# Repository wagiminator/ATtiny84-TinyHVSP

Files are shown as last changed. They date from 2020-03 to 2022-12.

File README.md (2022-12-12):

# TinyHVSP - High-Voltage Serial Programmer based on ATtiny24/44/84
Stand-alone high-voltage serial programmer and fuse resetter for ATtiny 13/25/45/85. This project was superseded by the more versatile [TinyCalibrator](https://github.com/wagiminator/ATtiny84-TinyCalibrator).

- Project Video (YouTube): https://youtu.be/2Q7D2RwkOMg
- Design Files (EasyEDA): https://easyeda.com/wagiminator/z-attiny84-tinyhvprogrammer

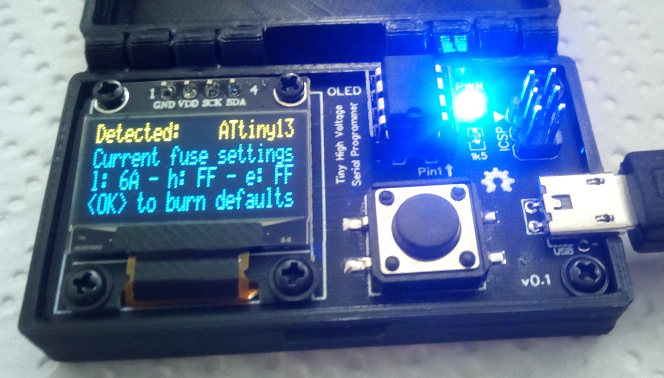
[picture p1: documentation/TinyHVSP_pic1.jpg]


# Hardware
The TinyHVSP is supplied with 5V via a [Micro USB connector](https://aliexpress.com/wholesale?SearchText=micro+usb+2pin+dip). The [ATtiny24/44/84](http://ww1.microchip.com/downloads/en/devicedoc/Atmel-7701_Automotive-Microcontrollers-ATtiny24-44-84_Datasheet.pdf) was chosen as the microcontroller for the TinyHVSP because it has the necessary number of GPIO pins. To generate the 12V for the High-Voltage Serial Programmer, an inexpensive [MT3608](https://datasheet.lcsc.com/szlcsc/XI-AN-Aerosemi-Tech-MT3608_C84817.pdf) boost converter IC was used. The 12V is controlled by a BJT and applied to the RESET pin of the target ATtiny if necessary. The remaining programming lines to the target are protected against a short circuit with resistors. The user interface utilizes one button and a [128x64 pixels OLED display](http://aliexpress.com/wholesale?SearchText=128+64+0.96+oled+new+4pin).

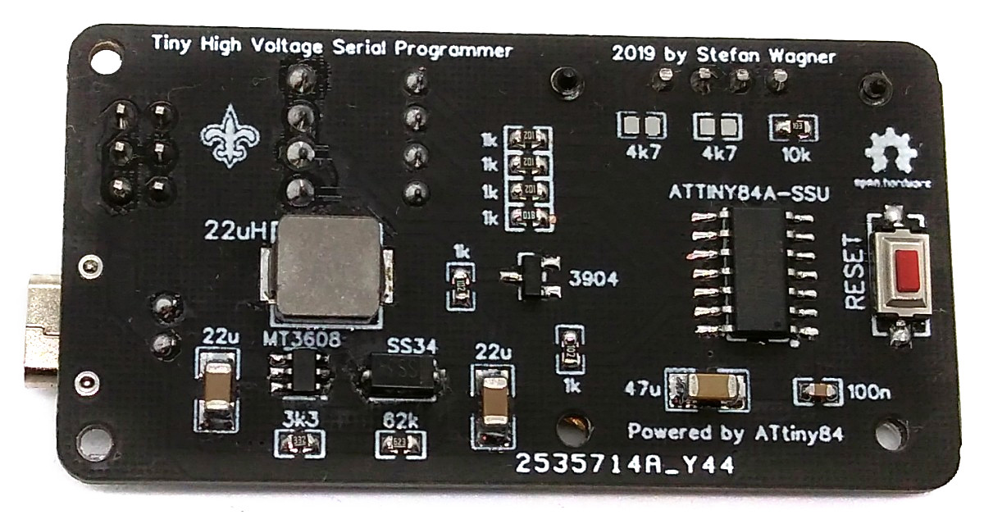
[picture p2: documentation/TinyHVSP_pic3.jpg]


# Software
## High-Voltage Serial Programmer
The code for the High-Voltage Serial Programmer (HVSP) is quite unspectacular. Simply put, for each action, a series of instructions are sent over the data lines to the target ATtiny and the corresponding response is read. The process and the instructions are well described in the data sheet.



## I²C OLED Implementation
The I²C protocol implementation is based on a crude bitbanging method. It was specifically designed for the limited resources of ATtiny10 and ATtiny13, but it works with some other AVRs (including the ATtiny24/44/84) as well. The functions for the OLED are adapted to the SSD1306 OLED module, but they can easily be modified to be used for other modules. In order to save resources, only the basic functionalities which are needed for this application are implemented. For a detailed information on the working principle of the I²C OLED implementation visit [TinyOLEDdemo](https://github.com/wagiminator/attiny13-tinyoleddemo).

## Compiling and Uploading
### If using the Arduino IDE
- Make sure you have installed [ATtinyCore](https://github.com/SpenceKonde/ATTinyCore).
- Go to **Tools -> Board -> ATtinyCore** and select **ATtiny24/44/84(a) (No bootloader)**.
- Go to **Tools** and choose the following board options:
  - **Chip:**           ATtiny24(a) or 44(a) or 84(a) (depending on your chip)
  - **Clock:**          8 MHz (internal)
  - **Millis/Micros:**  disabled
  - Leave the rest at the default settings
- Connect your programmer to your PC and to the ICSP header of the device.
- Go to **Tools -> Programmer** and select your ISP programmer (e.g. [USBasp](https://aliexpress.com/wholesale?SearchText=usbasp)).
- Go to **Tools -> Burn Bootloader** to burn the fuses.
- Open TinyHVSP sketch and click **Upload**.

### If using the precompiled hex-file
- Make sure you have installed [avrdude](https://learn.adafruit.com/usbtinyisp/avrdude).
- Connect your programmer to your PC and to the ICSP header of the device.
- Open a terminal.
- Navigate to the folder with the hex-file.
- Execute the following command (if necessary replace "t84" with the chip you use and "usbasp" with the programmer you use):
  ```
  avrdude -c usbasp -p t84 -U lfuse:w:0xe2:m -U hfuse:w:0xd7:m -U efuse:w:0xff:m -U flash:w:tinyhvsp.hex
  ```

### If using the makefile (Linux/Mac)
- Make sure you have installed [avr-gcc toolchain and avrdude](http://maxembedded.com/2015/06/setting-up-avr-gcc-toolchain-on-linux-and-mac-os-x/).
- Connect your programmer to your PC and to the ICSP header of the device.
- Open a terminal.
- Navigate to the folder with the makefile and the Arduino sketch.
- Run `DEVICE=attiny84 PROGRMR=usbasp make install` to compile, burn the fuses and upload the firmware (change DEVICE and PROGRMR accordingly).

# Operating Instructions
1. Connect a 5V power supply to the micro USB port.
2. Place the ATtiny13/25/45/85 in the IC socket. Use an [SOP adapter](https://aliexpress.com/wholesale?SearchText=sop-8+150mil+200mil+adapter) for SMD parts.
3. Press OK-button and follow the instructions on the display.

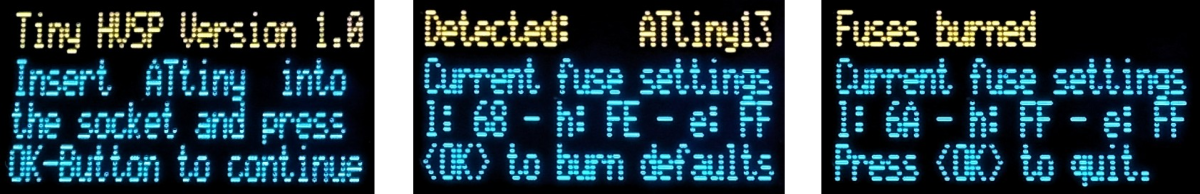
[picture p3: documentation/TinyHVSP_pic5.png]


# References, Links and Notes
1. [TinyCalibrator](https://github.com/wagiminator/ATtiny84-TinyCalibrator)
2. [AVR HVSP by Paul Willoughby](http://www.rickety.us/2010/03/arduino-avr-high-voltage-serial-programmer/)
3. [AVR HV Programmer by Jeff Keyzer](https://mightyohm.com/blog/2008/09/arduino-based-avr-high-voltage-programmer/)
4. [PiggyFuse by Ralph Doncaster](https://nerdralph.blogspot.com/2018/05/piggyfuse-hvsp-avr-fuse-programmer.html)
5. [I²C OLED Tutorial](https://github.com/wagiminator/attiny13-tinyoleddemo)
6. [ATtiny24/44/84 Datasheet](http://ww1.microchip.com/downloads/en/devicedoc/Atmel-7701_Automotive-Microcontrollers-ATtiny24-44-84_Datasheet.pdf)
7. [ATtiny13A Datasheet](http://ww1.microchip.com/downloads/en/DeviceDoc/doc8126.pdf)
8. [ATtiny25/45/85 Datasheet](https://ww1.microchip.com/downloads/en/DeviceDoc/Atmel-2586-AVR-8-bit-Microcontroller-ATtiny25-ATtiny45-ATtiny85_Datasheet.pdf)

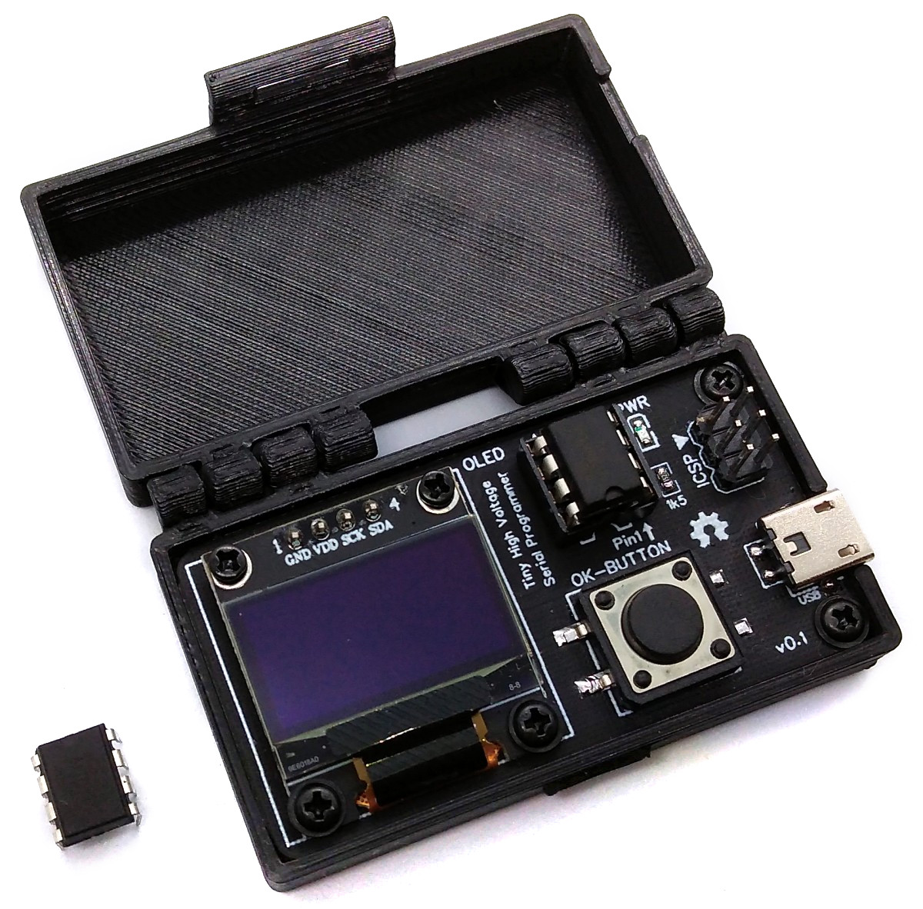
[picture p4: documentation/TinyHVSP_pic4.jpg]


# License


This work is licensed under Creative Commons Attribution-ShareAlike 3.0 Unported License. 
(http://creativecommons.org/licenses/by-sa/3.0/)

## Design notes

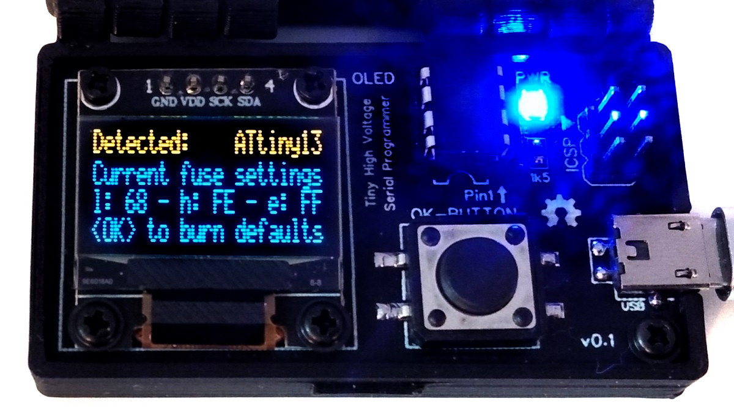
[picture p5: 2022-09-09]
documentation/TinyHVSP_pic2.jpg

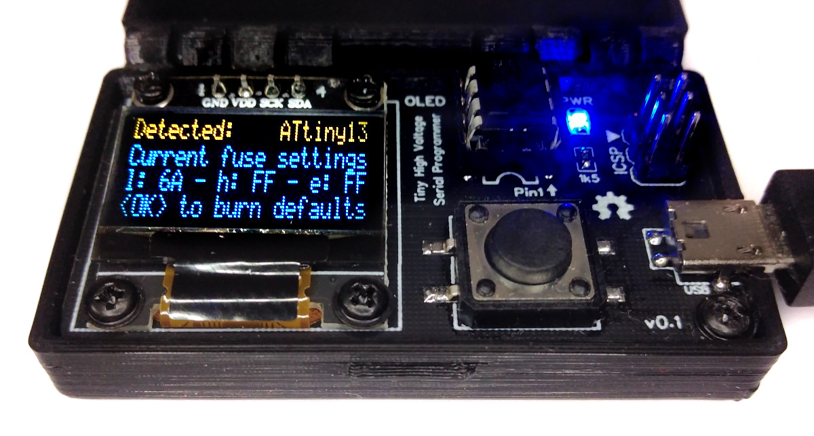
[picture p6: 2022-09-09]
documentation/TinyHVSP_pic6.jpg

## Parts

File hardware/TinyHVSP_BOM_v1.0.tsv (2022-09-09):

ID | Name | Designator | Footprint | Quantity | Manufacturer Part | Manufacturer | Supplier | Supplier Part
1 | 2n3904S | Q1 | SOT-23_1 | 1 | 2n3904S-RTK/PS | KEC | LCSC | C18536
2 | 22uH | L1 | IND-706628_IND_0630_VAN | 1 | 0630CDMCCDS-220MC | Sumida | LCSC | C167293
3 | 1k | R11,R10,R12,R13,R14 | 603 | 5 | 0603WAF1001T5E | UniOhm | LCSC | C21190
4 | 4k7 | R3,R4 | 603 | 2 | 0603WAF4701T5E | UniOhm | LCSC | C23162
5 | 62k | R5 | 603 | 1 | 0603WAF6202T5E | UniOhm | LCSC | C23221
6 | 1k5 | R2 | 603 | 1 | 0603WAF1501T5E | UniOhm | LCSC | C22843
7 | 10k | R1 | 603 | 1 | 0603WAF1002T5E | UniOhm | LCSC | C25804
8 | 3k3 | R6 | 603 | 1 | 0603WAF3301T5E | UniOhm | LCSC | C22978
9 | SMD-Tactile-Switch-12X12X6MM | SW1 | SW-SMD_4PIN-L12.0-W12.0-H6.0 | 1 | SMD Tactile Switch 12X12X6MM | ReliaPro | LCSC | C36226
10 | ATTINY84A-SSU | U1 | SOIC-14_150MIL | 1 | ATTINY84A-SSU | MICROCHIP | LCSC | C144333
11 | OLED | OLED | OLED | 1 | ?
12 | USB PWR Connector | USB | USB PWR CONNECTOR | 1 | KH-MICRO-SMT.J-2P | Shenzhen Kinghelm Elec | LCSC | C2688799
13 | MT3608 | U2 | SOT-23-6 | 1 | MT3608 | AEROSEMI | LCSC | C84817
14 | ICSP-6 | ICSP | ICSP-6-B | 1 | C65114 | BOOMELE | LCSC | C65114
15 | 3x6x2.5 | RESET | KEY-3.0*6.0 | 1 | 3x6x2.5Red head high temperature | ReliaPro | LCSC | C46491
16 | 100n | C1 | 603 | 1 | CC0603KRX7R9BB104 | YAGEO | LCSC | C14663
17 | 1k | R9 | 1206 | 1 | 1206W4F1001T5E | UniOhm | LCSC | C4410
18 | 47u | C2 | 1206 | 1 | 1206F476M160NT | FH | LCSC | C30300
19 | 22u | C3,C4 | 1206 | 2 | CL31A226KAHNNNE | SAMSUNG | LCSC | C12891
20 | PWR | LED1 | LED-0603 | 1 | 19-217/BHC-ZL1M2RY/3T | EVERLIGHT | LCSC | C72041
21 | SS34 | D1 | SMA(DO-214AC) | 1 | SS34 | Yenji | LCSC | C142458
22 | DIP8 Socket | ATTINY | DIP-8 | 1 | DS1009-08AT1NX-0A2 | CONNFLY | LCSC | C72124

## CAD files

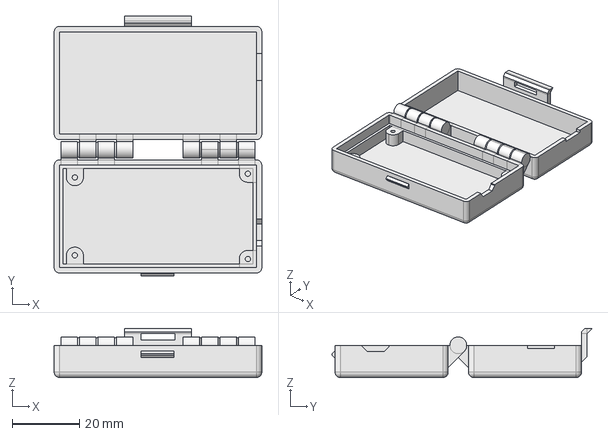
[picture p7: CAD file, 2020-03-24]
3dprint/TinyHVSP.fcstd
61.8 x 77.4 x 14.6 mm

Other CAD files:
3dprint/TinyHVSP.stl

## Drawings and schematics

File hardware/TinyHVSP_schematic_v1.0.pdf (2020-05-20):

ATtiny84 Microcontroller | Connectors

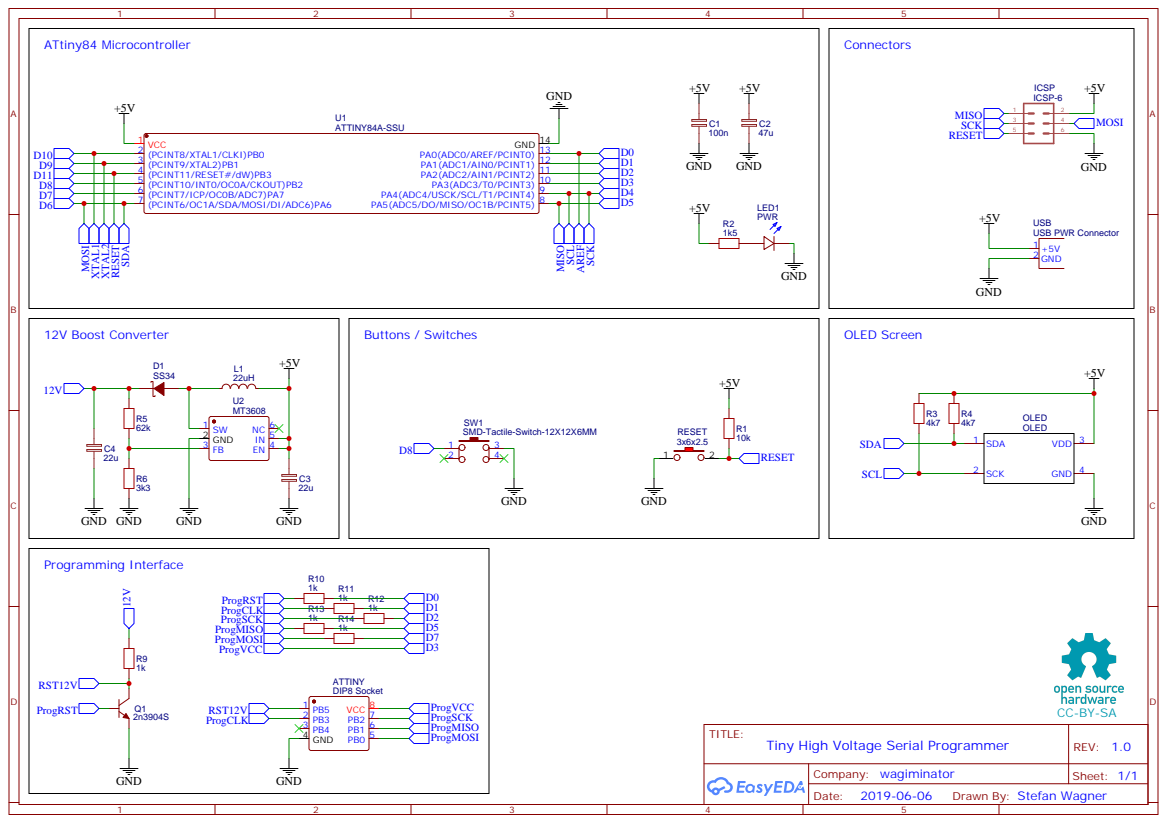
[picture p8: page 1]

Drawn By: Stefan Wagner

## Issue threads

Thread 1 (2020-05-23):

farbiges oled display

hspeedy, 2020-05-23:
welches display wurde hier verwendet? ich suche nach einem farbigen oled.
die bisher gefundenen waren immer monochrom.

wagiminator, 2022-11-24:
Das hier ist eigentlich auch monochrom: die erste Zeile wird immer gelb, der Rest wird immer blau dargestellt.

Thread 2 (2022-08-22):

Not working with attiny25/45/85

wareck, 2022-08-22:
I don't understand, it work perfectly with attiny13 but with tiny25 or tiny45 it do not work.
Have you got an idea to fix this ?

wagiminator, 2022-11-24:
That's weird. Can you otherwise program the ATtiny25/45 normally?

wareck, 2022-11-24:
Hello
sorry this message was old, I found why not working.
It's because I had some attiny25 which not have same signatures (probably fake or re-branded chips
I add a case switch with this weird signature and works perfectly

 I also add a dip socket and connections for attiny84 with the same design/software , I just add some line to recogneise chip and give right fuse for attiny84

 thanks you a lot
 you cas close this issue

best regards
Olivier

wagiminator, 2022-11-24:
Well that sounds good, thank you very much!

Closed 2022-11-24.

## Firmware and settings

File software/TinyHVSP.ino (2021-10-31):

// ===================================================================================
// Project:   TinyHVSP - AVR High-Voltage Serial Programmer based on ATtiny84
// Version:   v1.0
// Year:      2019
// Author:    Stefan Wagner
// Github:    https://github.com/wagiminator
// EasyEDA:   https://easyeda.com/wagiminator
// License:   http://creativecommons.org/licenses/by-sa/3.0/
// ===================================================================================
//
// Description:
// ------------
// Stand-alone AVR High-Voltage Serial Programmer for ATtiny13/25/45/85
// using an ATtiny84 for bit-banging the protocol according to the
// respective datasheets.
//
// References:
// -----------
// based on the work of Jeff Keyzer
// http://mightyohm.com
// and Paul Willoughby
// http://www.rickety.us/2010/03/arduino-avr-high-voltage-serial-programmer/
//
// The I²C OLED implementation is based on TinyOLEDdemo
// https://github.com/wagiminator/ATtiny13-TinyOLEDdemo
//
// OLED font was adapted from Neven Boyanov and Stephen Denne
// https://github.com/datacute/Tiny4kOLED
//
// Wiring:
// -------
//                                  +-\/-+
//                            Vcc  1|°   |14  GND
//              -------- XTAL PB0  2|    |13  PA0 ADC0 AREF --- TGT !RST 12V
//              -------- XTAL PB1  3|    |12  PA1 ADC1 AIN0 --- TGT SCI
//        RESET -------- !RST PB3  4|    |11  PA2 ADC2 AIN1 --- TGT SDO
//    OK Button -------- INT0 PB2  5|    |10  PA3 ADC3 T0 ----- TGT Vcc
//      TGT SDI -------- ADC7 PA7  6|    |9   PA4 ADC4 SCK ---- I2C SCK OLED
// I2C SDA OLED --- MOSI ADC6 PA6  7|    |8   PA5 ADC5 MISO --- TGT SII
//                                  +----+
//
// Compilation Settings:
// ---------------------

// Core:    ATtinyCore (https://github.com/SpenceKonde/ATTinyCore)
// Board:   ATtiny24/44/84(a) (No bootloader)
// Chip:    ATtiny24(a) or 44(a) or 84(a) (depending on your chip)
// Clock:   8 MHz (internal)
// Millis:  disabled
//
// Leave the rest on default settings. Don't forget to "Burn bootloader"!
// No Arduino core functions or libraries are used. Use the makefile if 
// you want to compile without Arduino IDE.
//
// Fuse settings: -U lfuse:w:0xe2:m -U hfuse:w:0xd5:m -U efuse:w:0xff:m


// ===================================================================================
// Libraries and Definitions
// ===================================================================================

// Libraries
#include <avr/io.h>       // for GPIO
#include <avr/pgmspace.h> // to store data in programm memory
#include <util/delay.h>   // for delays

// Pin definitions
#define RST_PIN   PA0     // 12V !RESET                       Pin 1 of target device
#define SCI_PIN   PA1     // Serial Clock Input (SCI)         Pin 2 of target device
#define SDO_PIN   PA2     // Serial Data Output (SDO)         Pin 7 of target device
#define SII_PIN   PA5     // Serial Instruction Input (SII)   Pin 6 of target device
#define SDI_PIN   PA7     // Serial Data Input (SDI)          Pin 5 of target device
#define VCC_PIN   PA3     // Target VCC                       Pin 8 of target device
#define I2C_SCL   PA4     // I2C Serial Clock (SCK)
#define I2C_SDA   PA6     // I2C Serial Data (SDA)
#define BUTTON    PB2     // OK-Button

// Global variables
uint8_t  inLFUSE, inHFUSE, inEFUSE;           // for reading fuses
uint8_t  outLFUSE, outHFUSE, outEFUSE;        // for writing fuses
uint8_t  inLOCK;                              // for reading lock bits
uint16_t signature;                           // for reading signature

// ===================================================================================
// I2C Implementation
// ===================================================================================

// I2C macros
#define I2C_SDA_HIGH()  DDRA &= ~(1<<I2C_SDA) // release SDA   -> pulled HIGH by resistor
#define I2C_SDA_LOW()   DDRA |=  (1<<I2C_SDA) // SDA as output -> pulled LOW  by MCU
#define I2C_SCL_HIGH()  DDRA &= ~(1<<I2C_SCL) // release SCL   -> pulled HIGH by resistor
#define I2C_SCL_LOW()   DDRA |=  (1<<I2C_SCL) // SCL as output -> pulled LOW  by MCU
#define I2C_DELAY()     asm("lpm")            // delay 3 clock cycles
#define I2C_CLOCKOUT()  I2C_SCL_HIGH();I2C_DELAY();I2C_SCL_LOW()  // clock out

// I2C init function
void I2C_init(void) {
  DDRA  &= ~((1<<I2C_SDA)|(1<<I2C_SCL));  // pins as input (HIGH-Z) -> lines released
  PORTA &= ~((1<<I2C_SDA)|(1<<I2C_SCL));  // should be LOW when as ouput
}

// I2C transmit one data byte to the slave, ignore ACK bit, no clock stretching allowed
void I2C_write(uint8_t data) {
  for(uint8_t i = 8; i; i--, data<<=1) {  // transmit 8 bits, MSB first
    (data & 0x80) ? (I2C_SDA_HIGH()) : (I2C_SDA_LOW());  // SDA HIGH if bit is 1
    I2C_CLOCKOUT();                       // clock out -> slave reads the bit
  }
  I2C_DELAY();                            // delay 3 clock cycles
  I2C_SDA_HIGH();                         // release SDA for ACK bit of slave
  I2C_CLOCKOUT();                         // 9th clock pulse is for the ignored ACK bit
}

// I2C start transmission
void I2C_start(uint8_t addr) {
  I2C_SDA_LOW();                          // start condition: SDA goes LOW first
  I2C_SCL_LOW();                          // start condition: SCL goes LOW second
  I2C_write(addr);                        // send slave address
}

// I2C stop transmission
void I2C_stop(void) {
  I2C_SDA_LOW();                          // prepare SDA for LOW to HIGH transition
  I2C_SCL_HIGH();                         // stop condition: SCL goes HIGH first
  I2C_SDA_HIGH();                         // stop condition: SDA goes HIGH second
}

// ===================================================================================
// OLED Implementation
// ===================================================================================

// OLED definitions
#define OLED_ADDR       0x78              // OLED write address
#define OLED_CMD_MODE   0x00              // set command mode
#define OLED_DAT_MODE   0x40              // set data mode
#define OLED_INIT_LEN   9                 // length of init command array

// OLED 5x8 pixels character set
const uint8_t OLED_FONT[] PROGMEM = {
  0x00, 0x00, 0x00, 0x00, 0x00, 0x00, 0x00, 0x2F, 0x00, 0x00, 0x00, 0x07, 0x00, 0x07, 0x00,
  0x14, 0x7F, 0x14, 0x7F, 0x14, 0x24, 0x2A, 0x7F, 0x2A, 0x12, 0x23, 0x13, 0x08, 0x64, 0x62,
  0x36, 0x49, 0x55, 0x22, 0x50, 0x00, 0x05, 0x03, 0x00, 0x00, 0x00, 0x1C, 0x22, 0x41, 0x00,
  0x00, 0x41, 0x22, 0x1C, 0x00, 0x14, 0x08, 0x3E, 0x08, 0x14, 0x08, 0x08, 0x3E, 0x08, 0x08,
  0x00, 0x00, 0xA0, 0x60, 0x00, 0x08, 0x08, 0x08, 0x08, 0x08, 0x00, 0x60, 0x60, 0x00, 0x00,
  0x20, 0x10, 0x08, 0x04, 0x02, 0x3E, 0x51, 0x49, 0x45, 0x3E, 0x00, 0x42, 0x7F, 0x40, 0x00,
  0x42, 0x61, 0x51, 0x49, 0x46, 0x21, 0x41, 0x45, 0x4B, 0x31, 0x18, 0x14, 0x12, 0x7F, 0x10,
  0x27, 0x45, 0x45, 0x45, 0x39, 0x3C, 0x4A, 0x49, 0x49, 0x30, 0x01, 0x71, 0x09, 0x05, 0x03,
  0x36, 0x49, 0x49, 0x49, 0x36, 0x06, 0x49, 0x49, 0x29, 0x1E, 0x00, 0x36, 0x36, 0x00, 0x00,
  0x00, 0x56, 0x36, 0x00, 0x00, 0x08, 0x14, 0x22, 0x41, 0x00, 0x14, 0x14, 0x14, 0x14, 0x14,
  0x00, 0x41, 0x22, 0x14, 0x08, 0x02, 0x01, 0x51, 0x09, 0x06, 0x32, 0x49, 0x59, 0x51, 0x3E,
  0x7C, 0x12, 0x11, 0x12, 0x7C, 0x7F, 0x49, 0x49, 0x49, 0x36, 0x3E, 0x41, 0x41, 0x41, 0x22,
  0x7F, 0x41, 0x41, 0x22, 0x1C, 0x7F, 0x49, 0x49, 0x49, 0x41, 0x7F, 0x09, 0x09, 0x09, 0x01,
  0x3E, 0x41, 0x49, 0x49, 0x7A, 0x7F, 0x08, 0x08, 0x08, 0x7F, 0x00, 0x41, 0x7F, 0x41, 0x00,
  0x20, 0x40, 0x41, 0x3F, 0x01, 0x7F, 0x08, 0x14, 0x22, 0x41, 0x7F, 0x40, 0x40, 0x40, 0x40,
  0x7F, 0x02, 0x0C, 0x02, 0x7F, 0x7F, 0x04, 0x08, 0x10, 0x7F, 0x3E, 0x41, 0x41, 0x41, 0x3E,
  0x7F, 0x09, 0x09, 0x09, 0x06, 0x3E, 0x41, 0x51, 0x21, 0x5E, 0x7F, 0x09, 0x19, 0x29, 0x46,
  0x46, 0x49, 0x49, 0x49, 0x31, 0x01, 0x01, 0x7F, 0x01, 0x01, 0x3F, 0x40, 0x40, 0x40, 0x3F,
  0x1F, 0x20, 0x40, 0x20, 0x1F, 0x3F, 0x40, 0x38, 0x40, 0x3F, 0x63, 0x14, 0x08, 0x14, 0x63,
  0x07, 0x08, 0x70, 0x08, 0x07, 0x61, 0x51, 0x49, 0x45, 0x43, 0x00, 0x7F, 0x41, 0x41, 0x00,
  0x02, 0x04, 0x08, 0x10, 0x20, 0x00, 0x41, 0x41, 0x7F, 0x00, 0x04, 0x02, 0x01, 0x02, 0x04,
  0x40, 0x40, 0x40, 0x40, 0x40, 0x00, 0x01, 0x02, 0x04, 0x00, 0x20, 0x54, 0x54, 0x54, 0x78,
  0x7F, 0x48, 0x44, 0x44, 0x38, 0x38, 0x44, 0x44, 0x44, 0x20, 0x38, 0x44, 0x44, 0x48, 0x7F,
  0x38, 0x54, 0x54, 0x54, 0x18, 0x08, 0x7E, 0x09, 0x01, 0x02, 0x18, 0xA4, 0xA4, 0xA4, 0x7C,
  0x7F, 0x08, 0x04, 0x04, 0x78, 0x00, 0x44, 0x7D, 0x40, 0x00, 0x40, 0x80, 0x84, 0x7D, 0x00,
  0x7F, 0x10, 0x28, 0x44, 0x00, 0x00, 0x41, 0x7F, 0x40, 0x00, 0x7C, 0x04, 0x18, 0x04, 0x78,
  0x7C, 0x08, 0x04, 0x04, 0x78, 0x38, 0x44, 0x44, 0x44, 0x38, 0xFC, 0x24, 0x24, 0x24, 0x18,
  0x18, 0x24, 0x24, 0x18, 0xFC, 0x7C, 0x08, 0x04, 0x04, 0x08, 0x48, 0x54, 0x54, 0x54, 0x20,
  0x04, 0x3F, 0x44, 0x40, 0x20, 0x3C, 0x40, 0x40, 0x20, 0x7C, 0x1C, 0x20, 0x40, 0x20, 0x1C,
  0x3C, 0x40, 0x30, 0x40, 0x3C, 0x44, 0x28, 0x10, 0x28, 0x44, 0x1C, 0xA0, 0xA0, 0xA0, 0x7C,
  0x44, 0x64, 0x54, 0x4C, 0x44, 0x08, 0x36, 0x41, 0x41, 0x00, 0x00, 0x00, 0x7F, 0x00, 0x00,
  0x00, 0x41, 0x41, 0x36, 0x08, 0x08, 0x04, 0x08, 0x10, 0x08, 0xFF, 0xFF, 0xFF, 0xFF, 0xFF
};

// OLED init settings
const uint8_t OLED_INIT_CMD[] PROGMEM = {
  0xC8, 0xA1,   // flip screen
  0xA8, 0x1F,   // set multiplex ratio
  0xDA, 0x02,   // set com pins hardware configuration
  0x8D, 0x14,   // set DC-DC enable
  0xAF          // display on
};

// OLED variables
uint8_t OLED_x, OLED_y;                   // current cursor position

// OLED init function
void OLED_init(void) {
  I2C_init();                             // initialize I2C first
  I2C_start(OLED_ADDR);                   // start transmission to OLED
  I2C_write(OLED_CMD_MODE);               // set command mode
  for(uint8_t i = 0; i < OLED_INIT_LEN; i++)
    I2C_write(pgm_read_byte(&OLED_INIT_CMD[i])); // send the command bytes
  I2C_stop();                             // stop transmission
}

// OLED set the cursor
void OLED_setCursor(uint8_t xpos, uint8_t ypos) {
  I2C_start(OLED_ADDR);                   // start transmission to OLED
  I2C_write(OLED_CMD_MODE);               // set command mode
  I2C_write(xpos & 0x0F);                 // set low nibble of start column
  I2C_write(0x10 | (xpos >> 4));          // set high nibble of start column
  I2C_write(0xB0 | (ypos & 0x07));        // set start page
  I2C_stop();                             // stop transmission
  OLED_x = xpos; OLED_y = ypos;           // set the cursor variables
}

// OLED clear line
void OLED_clearLine(uint8_t line) {
  OLED_setCursor(0, line);                // set cursor to line start
  I2C_start(OLED_ADDR);                   // start transmission to OLED
  I2C_write(OLED_DAT_MODE);               // set data mode
  for(uint8_t i=128; i; i--) I2C_write(0x00); // clear the line
  I2C_stop();                             // stop transmission
}

// OLED clear screen
void OLED_clearScreen(void) {
  for(uint8_t i=0; i<4; i++)              // 4 lines
    OLED_clearLine(i);                    // clear line
}

// OLED print a single character
void OLED_printChar(char c) {
  uint16_t ptr = c - 32;                  // character pointer
  ptr += ptr << 2;                        // -> ptr = (ch - 32) * 5;
  I2C_write(0x00);                        // write space between characters
  for(uint8_t i=5 ; i; i--) I2C_write(pgm_read_byte(&OLED_FONT[ptr++]));
  OLED_x += 6;                            // update cursor
  if(OLED_x > 122) {                      // line end ?
    I2C_stop();                           // stop data transmission
    OLED_setCursor(0,++OLED_y);           // set next line start
    I2C_start(OLED_ADDR);                 // start transmission to OLED
    I2C_write(OLED_DAT_MODE);             // set data mode
  }
}

// OLED print a string from program memory
void OLED_printPrg(const char* p) {
  I2C_start(OLED_ADDR);                   // start transmission to OLED
  I2C_write(OLED_DAT_MODE);               // set data mode
  char ch = pgm_read_byte(p);             // read first character from program memory
  while(ch) {                             // repeat until string terminator
    OLED_printChar(ch);                   // print character on OLED
    ch = pgm_read_byte(++p);              // read next character
  }
  I2C_stop();                             // stop transmission
}

// OLED convert byte nibble into hex character and prints it
void OLED_printNibble(uint8_t nibble) {
  char c;
  if(nibble <= 9)  c = '0' + nibble;
  else             c = 'A' + nibble - 10;
  OLED_printChar(c);
}

// OLED print byte as hex
void OLED_printHex(uint8_t value) {
  I2C_start(OLED_ADDR);                   // start transmission to OLED
  I2C_write(OLED_DAT_MODE);               // set data mode
  OLED_printNibble(value >> 4);           // print high nibble
  OLED_printNibble(value & 0x0F);         // print low nibble
  I2C_stop();                             // stop transmission
}

// ===================================================================================
// High-Voltage Serial Programmer Implementation
// ===================================================================================

// Desired fuse configuration (defaults) for ATtiny13
#define T13_LFUSE         0x6A
#define T13_HFUSE         0xFF

// Desired fuse configuration (defaults) for ATtiny25/45/85
#define Tx5_LFUSE         0x62
#define Tx5_HFUSE         0xDF

// Signatures
#define T13_SIG           0x9007
#define T25_SIG           0x9108
#define T45_SIG           0x9206
#define T85_SIG           0x930B

// HVSP macros
#define HVSP_RST_12V()    PORTA &= ~(1<<RST_PIN)
#define HVSP_RST_LOW()    PORTA |=  (1<<RST_PIN)
#define HVSP_VCC_ON()     PORTA |=  (1<<VCC_PIN)
#define HVSP_VCC_OFF()    PORTA &= ~(1<<VCC_PIN)
#define HVSP_SCI_HIGH()   PORTA |=  (1<<SCI_PIN)
#define HVSP_SCI_LOW()    PORTA &= ~(1<<SCI_PIN)
#define HVSP_SII_HIGH()   PORTA |=  (1<<SII_PIN)
#define HVSP_SII_LOW()    PORTA &= ~(1<<SII_PIN)
#define HVSP_SDI_HIGH()   PORTA |=  (1<<SDI_PIN)
#define HVSP_SDI_LOW()    PORTA &= ~(1<<SDI_PIN)
#define HVSP_SDO_REL()    DDRA  &= ~(1<<SDO_PIN)
#define HVSP_SDO_BIT      (PINA &   (1<<SDO_PIN))
#define HVSP_CLOCKOUT()   {HVSP_SCI_HIGH(); HVSP_SCI_LOW();}

// HVSP set up all control lines
void HVSP_init(void) {
  PORTA &= ~((1<<SCI_PIN) | (1<<SDO_PIN) | (1<<SII_PIN) | (1<<SDI_PIN) | (1<<VCC_PIN));
  PORTA |=   (1<<RST_PIN);
  DDRA  |=   (1<<SCI_PIN) | (1<<SDO_PIN) | (1<<SII_PIN) | (1<<SDI_PIN) | (1<<VCC_PIN) | (1<<RST_PIN);
}

// HVSP release all control lines (except RST)
void HVSP_release(void) {
  PORTA &= ~((1<<SCI_PIN) | (1<<SDO_PIN) | (1<<SII_PIN) | (1<<SDI_PIN) | (1<<VCC_PIN));
  DDRA  &= ~((1<<SCI_PIN) | (1<<SDO_PIN) | (1<<SII_PIN) | (1<<SDI_PIN) | (1<<VCC_PIN));
}

// HVSP enter the programming mode
void HVSP_enterProgMode(void) {
  HVSP_init();                            // initialize control lines
  HVSP_VCC_ON();                          // apply VCC to target
  _delay_us(20);                          // wait 20us
  HVSP_RST_12V();                         // apply 12V to RESET pin of target
  _delay_us(10);                          // wait 10us
  HVSP_SDO_REL();                         // release SDO line
  _delay_us(300);                         // delay 300us
}

// HVSP exit the programming mode
void HVSP_exitProgMode(void) {
  HVSP_SCI_LOW();                         // set SCI line LOW
  HVSP_RST_LOW();                         // RESET to 0V
  HVSP_VCC_OFF();                         // power down the target
  HVSP_release();                         // release all control lines
}

// HVSP send instruction and receive reply
uint8_t HVSP_sendInstr(uint8_t SDI_BYTE, uint8_t SII_BYTE) {
  uint8_t SDO_BYTE = 0;                   // received byte from target

  // wait until SDO_PIN goes high (target ready) or 10ms time-out
  for(uint8_t i=10; i; i--) {             // 10 x 1ms
    if(HVSP_SDO_BIT) break;               // check SDO line
    _delay_ms(1);                         // delay 1ms
  }
       
  // send start bit (SDI/SII = '0')
  HVSP_SDI_LOW();                         // SDI = '0'
  HVSP_SII_LOW();                         // SII = '0'
  HVSP_CLOCKOUT();                        // SCI HIGH, SCI LOW

  // send instruction bytes, MSB first; receive reply
  for(uint8_t i=8; i; i--) {
    (SDI_BYTE & 0x80) ? (HVSP_SDI_HIGH()) : (HVSP_SDI_LOW());
    (SII_BYTE & 0x80) ? (HVSP_SII_HIGH()) : (HVSP_SII_LOW());
    SDI_BYTE <<= 1;
    SII_BYTE <<= 1;
    SDO_BYTE <<= 1;
    if(HVSP_SDO_BIT) SDO_BYTE |= 1;
    HVSP_CLOCKOUT();
  }
      
  // send end bits (two times SDI/SII = '0')
  HVSP_SDI_LOW();                         // SDI = '0'
  HVSP_SII_LOW();                         // SII = '0'
  HVSP_CLOCKOUT();                        // SCI HIGH, SCI LOW
  HVSP_CLOCKOUT();                        // SCI HIGH, SCI LOW
        
  return SDO_BYTE;                        // return read SDO byte
}

// HVSP read signature of target device
void HVSP_readSignature(void) {
  HVSP_sendInstr(0x08, 0x4C);             // Instr1: read sig/calib command
  HVSP_sendInstr(0x01, 0x0C);             // Instr2: select signature byte 1
  HVSP_sendInstr(0x00, 0x68);             // Instr3: signature, not calibration
  signature = HVSP_sendInstr(0x00, 0x6C); // Instr4: read the signature byte
  signature <<= 8;                        // shift left 8 bits

  HVSP_sendInstr(0x02, 0x0C);             // Instr2: select signature byte 2
  HVSP_sendInstr(0x00, 0x68);             // Instr3: signature, not calibration
  signature |= HVSP_sendInstr(0x00, 0x6C);// Instr4: read the signature byte
}

// HVSP read lock bits
void HVSP_readLock(void) {
  HVSP_sendInstr(0x04, 0x4C);             // Instr1: read fuses/lock command
  HVSP_sendInstr(0x00, 0x78);             // Instr2: select lock bits
  inLOCK  = HVSP_sendInstr(0x00, 0x7C);   // Instr3: read lock bits
  inLOCK &= 0x03;                         // mask the lock bits
}

// HVSP read current fuse settings from target device
void HVSP_readFuses(void) {
  HVSP_sendInstr(0x04, 0x4C);             // Instr1: read fuses/lock command
  HVSP_sendInstr(0x00, 0x68);             // Instr2: select low fuse
  inLFUSE = HVSP_sendInstr(0x00, 0x6C);   // Instr3: read low fuse

  HVSP_sendInstr(0x00, 0x7A);             // Instr2: select high fuse
  inHFUSE = HVSP_sendInstr(0x00, 0x7E);   // Instr3: read high fuse

  HVSP_sendInstr(0x00, 0x6A);             // Instr2: select extended fuse
  inEFUSE = HVSP_sendInstr(0x00, 0x6E);   // Instr3: read extended fuse
}
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
int main(void) {
  // Setup
  DDRA  |= (1<<RST_PIN);                  // RST pin as ouput
  PORTA |= (1<<RST_PIN);                  // RST HIGH -> shut off 12V
  PORTB |= (1<<BUTTON);                   // pullup on button pin
  outEFUSE = 0xFF;                        // extended fuse default
  OLED_init();                            // setup I2C OLED
  OLED_clearScreen();                     // clear screen
  
  // Loop
  while(1) {
    // Print title screen    
    OLED_setCursor(0,0);
    OLED_printPrg(TitleScreen);
    
    // Start detection of device and repeat until positive detection
    uint8_t chipDetected = 0;             // assume negative detection by now
    while(!chipDetected) {                // repeat until a valid chip was detected
      waitButton();                       // wait for OK-Button pressed

      chipDetected = 1;                   // assume positive detection by now
      HVSP_enterProgMode();               // start programming mode
      HVSP_readSignature();               // read device signature

      // Prepare to show information on OLED
      OLED_setCursor(0,0);
      OLED_printPrg(DetectedStr);

      // Make settings depending on detected device
      switch(signature) {
        case T13_SIG: OLED_printPrg(ATtinyStr); OLED_printHex(0x13);
                      outLFUSE=T13_LFUSE; outHFUSE=T13_HFUSE; break;
        case T25_SIG: OLED_printPrg(ATtinyStr); OLED_printHex(0x25);
                      outLFUSE=Tx5_LFUSE; outHFUSE=Tx5_HFUSE; break;
        case T45_SIG: OLED_printPrg(ATtinyStr); OLED_printHex(0x45);
                      outLFUSE=Tx5_LFUSE; outHFUSE=Tx5_HFUSE; break;
        case T85_SIG: OLED_printPrg(ATtinyStr); OLED_printHex(0x85);
                      outLFUSE=Tx5_LFUSE; outHFUSE=Tx5_HFUSE; break;
        default:      OLED_printPrg(ErrorStr); OLED_setCursor(0,1);
                      OLED_printPrg(ErrorScreen); HVSP_exitProgMode();
                      chipDetected = 0; break;
      }
    }

    // Read and show detected fuse settings on OLED
    HVSP_readFuses();                     // read current fuse setting
    printFuses();                         // show detected fuse settings
    OLED_printPrg(DefaultStr);

    // Write and read back fuses
    waitButton();                         // wait for OK-Button pressed
    HVSP_writeFuses();                    // write default fuse settings
    HVSP_readFuses();                     // read back fuse settings

    // Check if fuses were burned correctly
    if( (inLFUSE != outLFUSE) | (inHFUSE != outHFUSE) ) {
      OLED_setCursor(0,0);
      OLED_printPrg(EraseScreen);
      waitButton();                       // wait for OK-Button pressed
      HVSP_eraseChip();                   // perform chip erase
      HVSP_writeFuses();                  // write default fuse settings
      HVSP_readFuses();                   // read back fuse settings
    }

    HVSP_exitProgMode();                  // exit programming mode

    // Write information on OLED
    OLED_setCursor(0,0);
    OLED_printPrg(BurnedStr);
    printFuses();
    OLED_printPrg(QuitStr);
    waitButton();                         // wait for OK-Button pressed 
  }
}

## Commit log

2020-11-18 Update files
    [TinyHVSP.fcstd, TinyHVSP.stl, TinyHVSP_BOM_v1.0.tsv]
2022-09-09 Update BOM
    [TinyHVSP_BOM_v1.0.tsv]
